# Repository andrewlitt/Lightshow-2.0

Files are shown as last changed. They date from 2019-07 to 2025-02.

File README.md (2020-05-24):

# Lightshow-2.0
KiCAD Project Files for a PCB to control LED's through Music! Uses MSGEQ7 + ATmega328P w/ an Arduino Bootloader!

[I wrote about this project on my blog!](https://alitt.ca/blog/led-music/)



[render]: https://andrewlitt.github.io/2019/08/11/LED-Music/header.png "PCB Rendering"

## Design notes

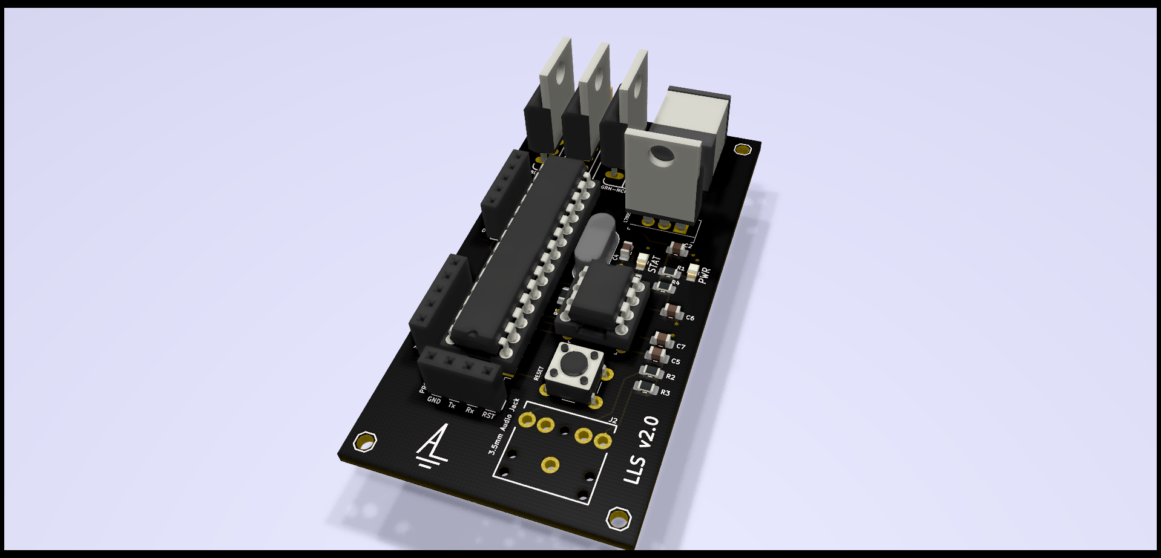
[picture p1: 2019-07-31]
Gerber Files/Black.png

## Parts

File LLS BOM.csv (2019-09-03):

Description | Manufacturer Part Number | Manufacturer | Digi-Key Part Number | Packaging | Part Status | Quantity | Unit Price | Extended Price | Quantity Available | Mfg Std Lead Time | RoHS Status | Lead Free Status | REACH Status
CONN JACK STEREO 3.5MM R/A | SJ1-3525NG | CUI Inc. | CP1-3525NG-ND | Tray | Active | 1 | 1.17 | $1.17 | 7885 | 6 Weeks | RoHS Compliant | Lead free | Not Available
CONN PWR JACK 2X5.5MM SOLDER | PJ-102A | CUI Inc. | CP-102A-ND | Tray | Active | 1 | 0.91 | $0.91 | 90996 | 6 Weeks | RoHS Compliant | Lead free | Not Available
CONN HDR 5POS 0.1 TIN PCB | PPTC051LFBN-RC | Sullins Connector Solutions | S6103-ND | Tray | Active | 2 | 0.67 | $1.34 | 24441 | 5 Weeks | ROHS3 Compliant | Lead free | REACH Unaffected
CONN HDR 4POS 0.1 TIN PCB | PPTC041LFBN-RC | Sullins Connector Solutions | S7002-ND | Tray | Active | 2 | 0.64 | $1.28 | 25758 | 5 Weeks | ROHS3 Compliant | Lead free | REACH Unaffected
CONN IC DIP SOCKET 8POS TIN | A 08-LC-TT | Assmann WSW Components | AE9986-ND | Tube | Active | 1 | 0.26 | $0.26 | 58954 | 20 Weeks | Not Available | Lead free | REACH Unaffected
CONN IC DIP SOCKET 28POS TIN | ED281DT | On Shore Technology Inc. | ED3050-5-ND | Tube | Active | 1 | 0.47 | $0.47 | 12079 | 8 Weeks | Not Available | Lead free | REACH Unaffected
CRYSTAL 16.0000MHZ 20PF T/H | 9B-16.000MBBK-B | TXC CORPORATION | 887-2015-ND | Bulk | Active | 1 | 0.45 | $0.45 | 2894 | 13 Weeks | RoHS Compliant | Lead free | Not Available
IC MCU 8BIT 32KB FLASH 28DIP | ATMEGA328P-PU | Microchip Technology | ATMEGA328P-PU-ND | Tube | Active | 1 | 3.24 | $3.24 | 9121 | 7 Weeks | Not Available | Lead free | REACH Unaffected
IC REG LINEAR 5V 1.5A TO220AB | L7805CV | STMicroelectronics | 497-1443-5-ND | Tube | Active | 1 | 0.76 | $0.76 | 46383 | 6 Weeks | ROHS3 Compliant | Lead free | REACH Unaffected
MOSFET N-CH 60V 32A TO-220 | FQP30N06L | ON Semiconductor | FQP30N06L-ND | Tube | Active | 3 | 1.82 | $5.46 | 11313 | 4 Weeks | ROHS3 Compliant | Lead free | REACH Unaffected
SWITCH TACTILE SPST-NO 0.05A 24V | B3F-1000 | Omron Electronics Inc-EMC Div | SW400-ND | Bulk | Active | 1 | 0.41 | $0.41 | 23126 | 13 Weeks | RoHS Compliant | Lead free | Not Available
RES SMD 10K OHM 0.1% 1/8W 0805 | ERA-6AEB103V | Panasonic Electronic Components | P10KDACT-ND | Cut Tape (CT) | Active | 1 | 0.55 | $0.55 | 940600 | 17 Weeks | RoHS Compliant | Lead free | REACH Unaffected
RES SMD 220 OHM 0.1% 1/8W 0805 | ERA-6AEB221V | Panasonic Electronic Components | P220DACT-ND | Cut Tape (CT) | Active | 2 | 0.55 | $1.10 | 118493 | 17 Weeks | RoHS Compliant | Lead free | REACH Unaffected
RES SMD 22K OHM 0.5% 1/4W 0805 | ERJ-PB6D2202V | Panasonic Electronic Components | P21169CT-ND | Cut Tape (CT) | Active | 2 | 0.38 | $0.76 | 15468 | 18 Weeks | ROHS3 Compliant | Lead free | Not Available
RES SMD 200K OHM 0.1% 1/8W 0805 | ERA-6AEB204V | Panasonic Electronic Components | P200KDACT-ND | Cut Tape (CT) | Active | 1 | 0.55 | $0.55 | 67582 | 17 Weeks | RoHS Compliant | Lead free | REACH Unaffected
CAP CER 22PF 50V C0G/NP0 0805 | CL21C220JB61PNC | Samsung Electro-Mechanics | 1276-2605-1-ND | Cut Tape (CT) | Active | 2 | 0.28 | $0.56 | 230182 | Not Available | ROHS3 Compliant | Lead free | REACH Unaffected
CAP CER 33PF 50V C0G/NP0 0805 | CL21C330JBANNNC | Samsung Electro-Mechanics | 1276-1105-1-ND | Cut Tape (CT) | Active | 1 | 0.14 | $0.14 | 360479 | Not Available | ROHS3 Compliant | Lead free | REACH Unaffected
CAP CER 0.1UF 50V Y5V 0805 | CL21F104ZBCNNNC | Samsung Electro-Mechanics | 1276-1007-1-ND | Cut Tape (CT) | Active | 5 | 0.14 | $0.70 | 4739532 | Not Available | ROHS3 Compliant | Lead free | REACH Unaffected
CAP CER 10UF 25V X5R 0805 | CL21A106KAFN3NE | Samsung Electro-Mechanics | 1276-2890-1-ND | Cut Tape (CT) | Active | 2 | 0.4 | $0.80 | 341178 | Not Available | ROHS3 Compliant | Lead free | REACH Unaffected
LED GREEN DIFFUSED 0805 SMD | LG R971-KN-1 | OSRAM Opto Semiconductors Inc. | 475-1410-1-ND | Cut Tape (CT) | Active | 1 | 0.44 | $0.44 | 181720 | 12 Weeks | ROHS3 Compliant | Lead free | REACH Unaffected
LED YELLOW DIFFUSED 0805 SMD | LY R976-PS-36 | OSRAM Opto Semiconductors Inc. | 475-2560-1-ND | Cut Tape (CT) | Active | 1 | 0.47 | $0.47 | 57422 | 12 Weeks | ROHS3 Compliant | Lead free | REACH Unaffected
BRASS SPACER STUD METRIC THREAD | 970050244 | Wurth Electronics Inc. | 732-12789-ND | Bulk | Active | 1 | 0.54 | $0.54 | 250 | 17 Weeks | Not Available | Lead free | Not Available
BRASS SPACER STUD METRIC THREAD | 971100244 | Wurth Electronics Inc. | 732-12918-ND | Bulk | Active | 1 | 0.88 | $0.88 | 2755 | 17 Weeks | Not Available | Lead free | Not Available

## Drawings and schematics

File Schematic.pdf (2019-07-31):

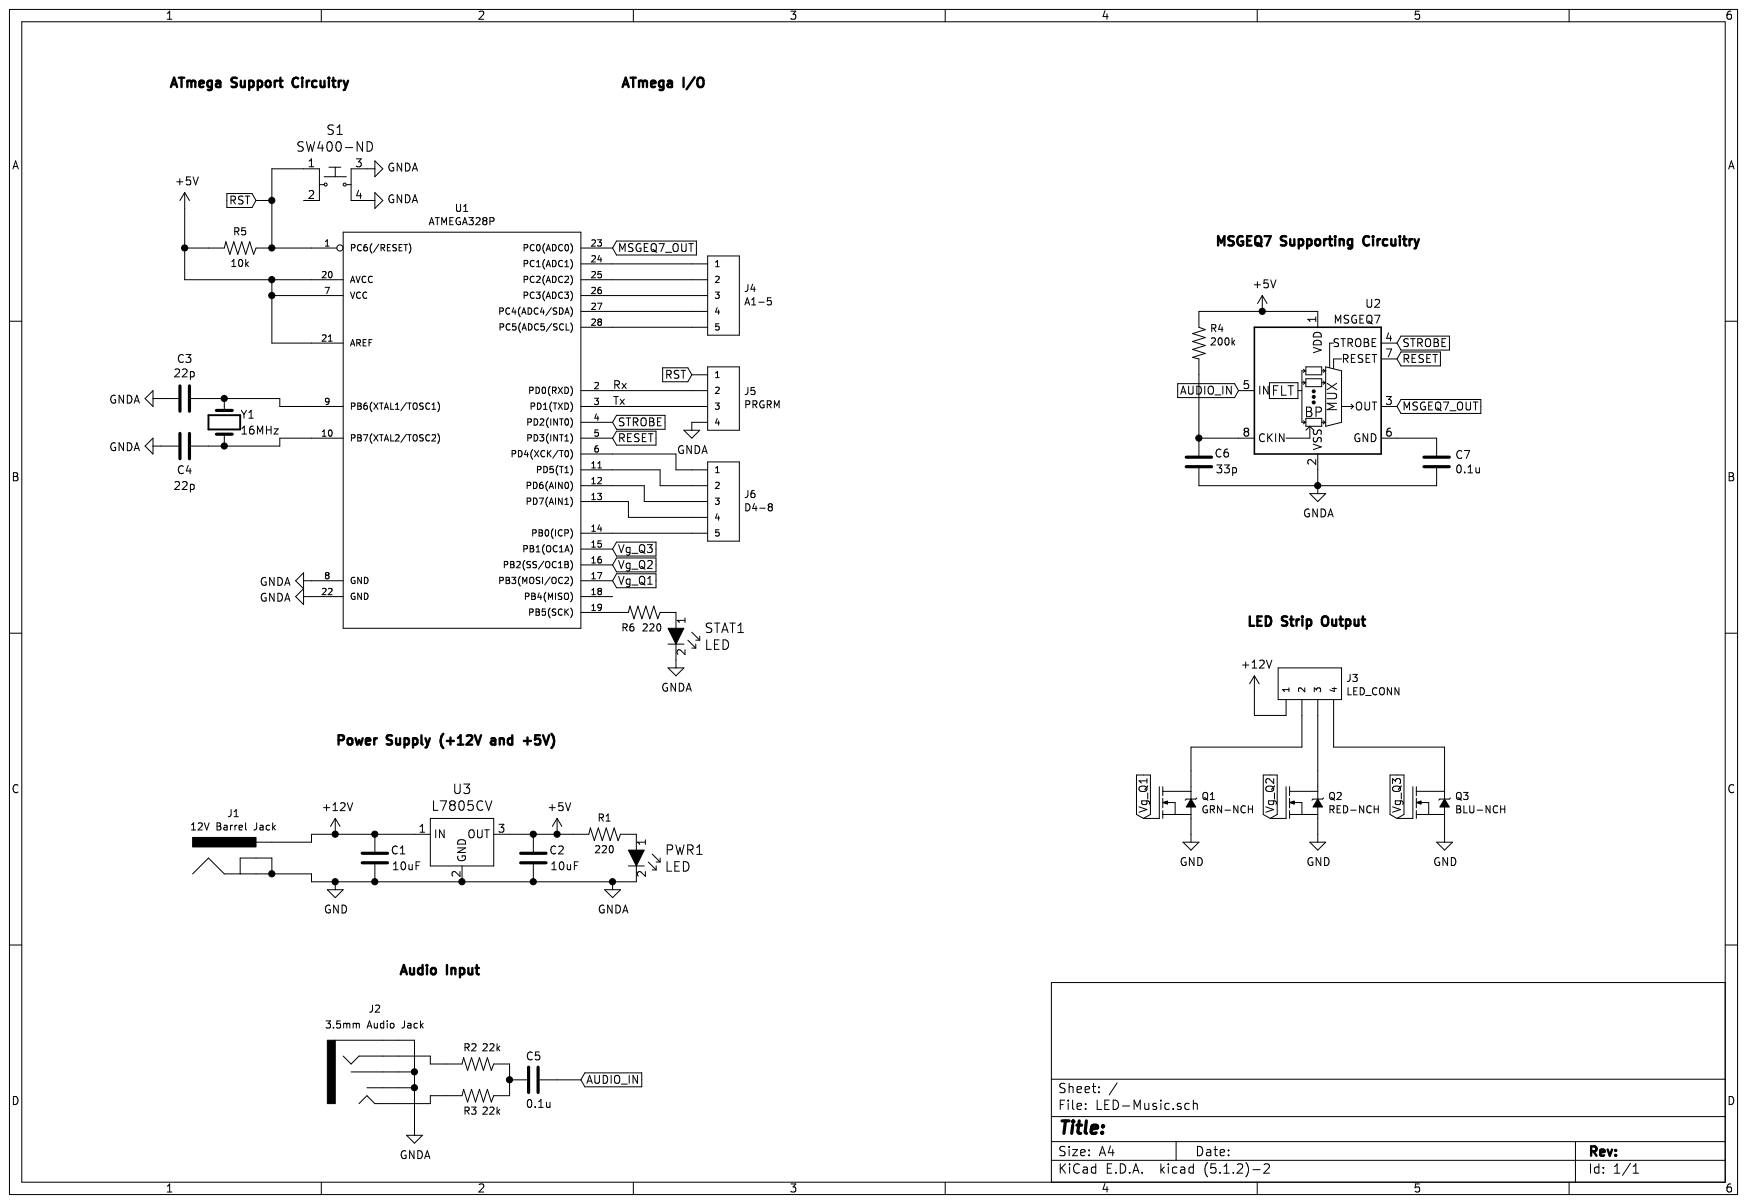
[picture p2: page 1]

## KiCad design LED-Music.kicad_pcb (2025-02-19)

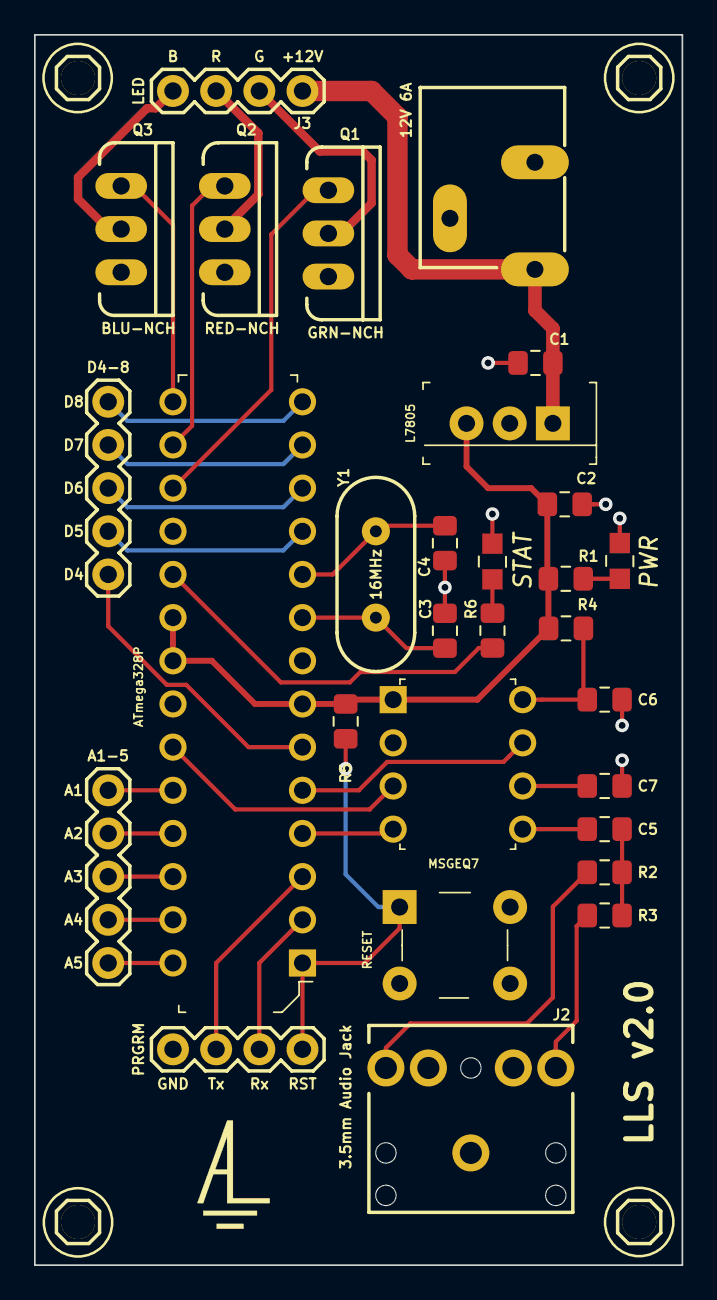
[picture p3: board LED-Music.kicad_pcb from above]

Board: 2 copper layers, 38.1 x 72.4 mm, 34 parts (0 on the bottom side), 36 nets.

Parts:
 : 1X01
 #2,  #3,  #4: 1X01
ATmega328P: ATMEGA328P; DIP-28_W7.62mm
C1, C2: 10uF; C_0805_2012Metric_Pad1.15x1.40mm_HandSolder
C3, C4: 22p; C_0805_2012Metric_Pad1.15x1.40mm_HandSolder
C5, C7: 0.1u; C_0805_2012Metric_Pad1.15x1.40mm_HandSolder
C6: 33p; C_0805_2012Metric_Pad1.15x1.40mm_HandSolder
J1: 12V 6A; POWER_JACK_SLOT
J2: 3.5mm Audio Jack; AUDIO-JACK
J3: LED; 1X04
J4: A1-5; 1X05
J5: PRGRM; 1X04
J6: D4-8; 1X05
L7805: L7805CV; TO-220-3
MSGEQ7: MSGEQ7; DIP-8_W7.62mm
PWR: LED; 0805
Q1: GRN-NCH; TO220V
Q2: RED-NCH; TO220V
Q3: BLU-NCH; TO220V
R1, R6: 220; R_0805_2012Metric_Pad1.15x1.40mm_HandSolder
R2, R3: 22k; R_0805_2012Metric_Pad1.15x1.40mm_HandSolder
R4: 200k; R_0805_2012Metric_Pad1.15x1.40mm_HandSolder
R5: 10k; R_0805_2012Metric_Pad1.15x1.40mm_HandSolder
RESET: SW400-ND; Switch_Tactile_THT_B3F-1xxx
STAT: LED; 0805
Y1: 16MHz; HC49US
m: LOGO; logo

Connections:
+5V: ATmega328P.7, ATmega328P.20, ATmega328P.21, C2.1, L7805.3, MSGEQ7.1, R1.2, R4.1, R5.2
+12V: C1.1, J1.PWR, J3.1, L7805.1
/Rx: ATmega328P.2, J5.2
/Tx: ATmega328P.3, J5.3
AUDIO_IN: C5.1, MSGEQ7.5
GND: ATmega328P.8, ATmega328P.22, C1.2, C2.2, C3.2, C4.2, C6.1, C7.2, J1.GND@, J2.RSH, J2.SLEE, J2.TSH, J5.4, L7805.2, MSGEQ7.2, PWR.2, Q1.3, Q2.3, Q3.3, RESET.3, RESET.4, STAT.2
MSGEQ7_OUT: ATmega328P.23, MSGEQ7.3
unnamed: ATmega328P.9, C3.1, Y1.1
unnamed: ATmega328P.10, C4.1, Y1.2
unnamed: C5.2, R2.1, R3.1
unnamed: C6.2, MSGEQ7.8, R4.2
unnamed: C7.1, MSGEQ7.6
unnamed: J2.RING, R2.2
unnamed: J2.TIP, R3.2
unnamed: J3.2, Q1.2
unnamed: J3.3, Q2.2
unnamed: J3.4, Q3.2
unnamed: ATmega328P.24, J4.1
unnamed: ATmega328P.25, J4.2
unnamed: ATmega328P.26, J4.3
unnamed: ATmega328P.27, J4.4
unnamed: ATmega328P.28, J4.5
unnamed: ATmega328P.6, J6.1
unnamed: ATmega328P.11, J6.2
unnamed: ATmega328P.12, J6.3
unnamed: ATmega328P.13, J6.4
unnamed: ATmega328P.14, J6.5
unnamed: PWR.1, R1.1
unnamed: R6.1, STAT.1
unnamed: ATmega328P.19, R6.2
RESET: ATmega328P.5, MSGEQ7.7
RST: ATmega328P.1, J5.1, R5.1, RESET.1
STROBE: ATmega328P.4, MSGEQ7.4
Vg_Q1: ATmega328P.17, Q1.1
Vg_Q2: ATmega328P.16, Q2.1
Vg_Q3: ATmega328P.15, Q3.1

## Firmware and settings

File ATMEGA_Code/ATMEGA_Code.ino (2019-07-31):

// Program parameters
#define avg  8            // Window of moving average
int thres = 25;         // Threshold to activate channel
double redScalar = 1.25;   // Red multiplier
double bluScalar = 1.4;    // Blue multiplier
double grnScalar = 0.8;    // Green multiplier

// Configuration
int analogPin = 0; // A0
int strobePin = 2; // D2
int resetPin = 3;  // D3
int redPin = 10;   // D10
int grnPin = 11;   // D11
int bluPin =  9;   // D9

int spectrumValue[7];
int val[3] = {0,0,0};
int pins[3] = {redPin,grnPin,bluPin};
double scalar[3] = {redScalar,grnScalar,bluScalar};
int prevVal[avg][3];

void setup()
{
     Serial.begin(9600);
     pinMode(analogPin, INPUT);
     pinMode(strobePin, OUTPUT);
     pinMode(resetPin, OUTPUT);
     analogReference(DEFAULT);

     digitalWrite(resetPin, LOW);
     digitalWrite(strobePin, HIGH);

     LightStartup();

     delay(20);
     for(int p = 0; p < 3; p++){
        for(int v = 0; v < avg; v++){
          prevVal[v][p] = 0;
        }
     }
}

void loop()
{
    digitalWrite(resetPin, HIGH);
    digitalWrite(resetPin, LOW);

    for (int i = 0; i < 7; i++){
         digitalWrite(strobePin, LOW);
         delayMicroseconds(30); // to allow the output to settle
         spectrumValue[i] = analogRead(analogPin);
         //PrintValue(spectrumValue[i]);
         digitalWrite(strobePin, HIGH);
    }
    //Serial.println();
    val[0] =  map(spectrumValue[0], 0, 1023, 0, 255);
    val[1] =  map(spectrumValue[3], 0, 1023, 0, 255);
    val[2] =  map(spectrumValue[6], 0, 1023, 0, 255);

    // For each channel value
    for(int p = 0; p < 3; p++){

      
      // Set to 0 if output below a threshold
      if(val[p] < thres) val[p] = 0;

      // Multiply by channel scalar (Goal: Boost Red & Blu, subdue Grn)
      double d = val[p];
      d *= scalar[p];
      val[p] = (int) d;
      
      // Shift the Value history back one entry
      for(int v = 0; v < avg-1; v++) prevVal[v][p] = prevVal[v+1][p];
      prevVal[0][p] = val[p];

      // Adjust the value according to a moving average of past X samples
      int  tmp = 0;
      for(int v = 0; v < avg; v++) tmp += prevVal[v][p];
      val[p] = tmp/avg;
      PrintValue(val[p]);
    }
    Serial.println();
    // Write the outputs
    for(int p = 0; p < 3; p++) analogWrite(pins[p],val[p]);
    delay(10);
}

void PrintValue(int val){
    if (val < 10){
        Serial.print("   ");
        Serial.print(val);
    }
    else if (val < 100){
        Serial.print("  ");
        Serial.print(val);
    }
    else{
        Serial.print(" ");
        Serial.print(val);
    }
}

void LightStartup(){
  for(int p = 0; p < 3; p++){
      for (int i = 0; i < 255; i++){
         analogWrite(pins[p], i);
         delay(1);
      }
      for (int i = 255; i > 0; i--){
         analogWrite(pins[p], i);
         delay(1);
      }
  }
}

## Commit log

2019-07-31 Project Upload
    [LED-Music-B_Cu.gbl, LED-Music-B_Mask.gbs, LED-Music-B_Paste.gbp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]
2025-02-19 IMP: Update to KiCAD 8.0 File Formats
    [LED-Music.kicad_pcb, LED-Music.kicad_sch]
